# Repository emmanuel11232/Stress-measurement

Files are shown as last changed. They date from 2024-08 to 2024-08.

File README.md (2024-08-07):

# Wearable-device-for-stress-measurement-through-cardiac-parameters
Implemented a design of a device that can be used easily and comfortably, where physiological values are indicated such as body temperature, heart rate and variability heart rate, in addition to indicating the person's stress level at the time. A circuit controlled by a ProTrinket, in addition to a watch-like casing design.

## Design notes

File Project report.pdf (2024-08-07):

MUNOZ, JIMENEZ, DISPOSITIVO WEARABLE PARA EVALUACI ˜ | ON DEL ESTR ´ | ES MEDIANTE PAR ´ | AMETROS CARD ´ | ÍACOS | 1
Dispositivo wearable para evaluacion del estr ´ | es´
| mediante parametros card ´ | | | íacos
Emmanuel Munoz Pe ˜ | na, Nicole Jimenez Herrera ˜
emmanuel111232@estudiantec.cr nicojh@estudiantec.cr
Area acad ´ | emica de Ingenier ´ | ía Mecatronica ´
Instituto Tecnologico de Costa Rica ´

Resumen—Es importante tener un control del estres debido a ´ que puede afectar negativamente la salud física y emocional, así como el rendimiento academico y laboral. Al manejar el ´ estres de manera efectiva, se puede mejorar la calidad de vida y ´ bienestar en general, de ahí la importancia de un dispositivo que pueda alertar a la persona que esta pasando por un momento de ´
estres, as ´ | í poder tomar acciones y tecnicas de relajaci ´ | on. Para ´
ello, se implemento un dise ´ | no de un dispositivo que pueda ser ˜
utilizado facil y c ´ | omodamente, donde indique valores fisiol ´ | ogicos ´
como la temperatura corporal, frecuencia cardíaca y variabilidad
cardiaca, ademas de indicar el nivel de estr ´ | es de la persona ´
en el momento. Se implementa un circuito controlado por un
ProTrinket, ademas del dise ´ | no de una carcasa similar a un reloj ˜
inteligente. Finalmente, se realizaron pruebas durante el juego
Osu! dando como resultados la parametrizacion del estr ´ | es para ´
poder activar las alarmas.

Palabras clave—Dispositivo wearable, Estres, Frecuencia ´ cardíaca, Variabilidad cardíaca,

I. INTRODUCCION´
A lo largo de esta investigacion se desarroll ´ | o un dispo- ´
sitivo capaz de dar una monitorizacion continua y a largo ´ plazo de la variabilidad cardiaca, la frecuencia cardiaca y la temperatura corporal, lo que permite capturar variaciones y tendencias en el ritmo cardíaco y su relacion con los estresores ´
psicologicos y f ´ | ísicos. Ademas, al ser port ´ | atil y f ´ | acil de usar, ´
el dispositivo se integra perfectamente en la vida cotidiana del usuario, brindando una experiencia comoda y no intrusiva. Se ´
presentaran en detalle el dise ´ | no y el desarrollo del dispositivo ˜
wearable, incluyendo su arquitectura, los componentes clave y los algoritmos utilizados para el analisis de los datos. ´
De acuerdo con [1], la tecnología wearable se define como dispositivos usados en el cuerpo o en la ropa los cuales van a consistir de un receptor y un transductor los cuales
convierten las variables físicas en una senal ˜ | util para el ´
analisis digital. Entre estas nuevas tecnolog ´ | ías destaca el auge
por la monitorizacion y variabilidad card ´ | íaca. La frecuencia
cardíaca y la variabilidad de la frecuencia cardíaca (VFC) se han convertido en indicadores cruciales para evaluar la salud cardiovascular y la salud general de un individuo [2]. El calculo del VFC se puede realizar de diferentes formas, sin ´
embargo, una de las mas usadas es el valor cuadr ´ | atico medio ´
de diferencias sucesivas o RMSSD por sus siglas en ingles, ´ que como lo define [3] “es la raíz cuadrada del valor medio de la suma de las diferencias al cuadrado de todos los intervalos RR sucesivos”.

Asimismo, como lo menciona [3] si se tiene una disminu-
cion en el VFC con un aumento de la frecuencia card ´ | | | | íaca
va a dar un indicativo de fatiga o estres, adem ´ | as, se ve ´
que si se tiene una disminucion de ambas, puede deberse ´
a acumulacion de estr ´ | es. Se tiene que esta es una medida ´
sensible a las respuestas rapidas del SNA a est ´ | ímulos agudos
de estres, como el ejercicio f ´ | ísico intenso o situaciones de
estres emocional. Esto se debe a que el RMSSD mide la ´ variabilidad de corto plazo de la frecuencia cardíaca, que está influenciada principalmente por la actividad parasimpatica. ´ Adjuntando a estas mediciones la temperatura corporal se
puede obtener informacion sobre el estado psicol ´ | ogico de una ´
persona, así como la respuesta a estresores ya sea físicos o
psicologicos. Como lo muestra [4] hay una relaci ´ | on estrecha ´
entre los valores de variacion de frecuencia card ´ | íaca y el nivel
de estres psicol ´ | ogico de un individuo, de la misma forma que ´
la frecuencia cardiaca y la temperatura tienen una relacion con ´ estos, teniendo un aumento dependiendo del nivel de estres en ´ el individuo como se puede ver en lo mostrado por [5] y [6].
| II. DESCRIPCION DEL PROBLEMA ´
Para la implementacion de Monitor de Estr ´ | es se tienen dife- ´
rentes retos. El primeramente, ¿como hacer que el dispositivo ´
sea pequeno y c ˜ | omodo?. Adem ´ | as, ¿cu ´ | al modelo matem ´ | atico ´
utilizar para relacionar los valores fisiologicos de temperatura, ´ frecuencia y variabilidad cardíaca?. Tomando en consideracion los problemas planteados y el alcance de comodidad y ´ economico, se enlistan los criterios y restricciones para los ´ componentes. En general, se delimitan que los componentes
sean lo mas peque ´ | nos posibles, para comodidad, y de un precio ˜
accesible. Específicamente para el sensor de temperatura se delimita que tenga una tolerancia de < ±0,5 °C, el microcontrolador debe tener las entradas y salidas suficientes para controlar la alarma y el display y medir los datos de ambos sensores. Para la alarma, se busco que tuviera al menos 3 ´ modos de diferenciar los 3 estados de estres bajo, medio y ´ alto. Y finalmente, que todos los componentes requirieran aproximadamente de 3,3 V para solamente utilizar una batería LiPo.
III. IMPLEMENTACION DE LA SOLUCI ´ | ON´
La construccion del prototipo se divide en tres grandes ´
areas: el circuito el ´ | ectrico, con los componentes el ´ | ectricos y ´
conexiones; componentes físicos,; codigo de microcontrolador, ´ es la logica de toma de datos y el control de los actuadores. ´

MUNOZ, JIMENEZ, DISPOSITIVO WEARABLE PARA EVALUACI ˜ | ON DEL ESTR ´ | ES MEDIANTE PAR ´ | AMETROS CARD ´ | ÍACOS | 2

III-A. Circuito electrico ´

En la Fig. 1 se muestra el circuito electrico final utilizado ´ en el prototipo, donde ademas de las conexiones de todos los ´ dispositivos se detallan los pines a utilizar el microcontrolador. Por otra parte, para entender de mejor forma la conexion, se ´ puede ver el diagrama de bloques en la Fig. 2

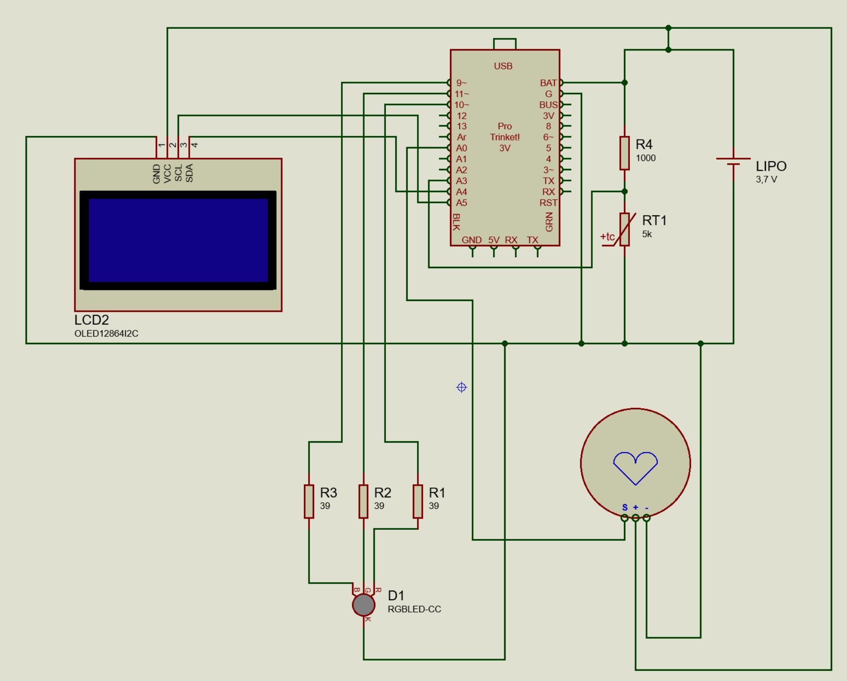
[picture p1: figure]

Figura 1. Circuito electrico implementado ´

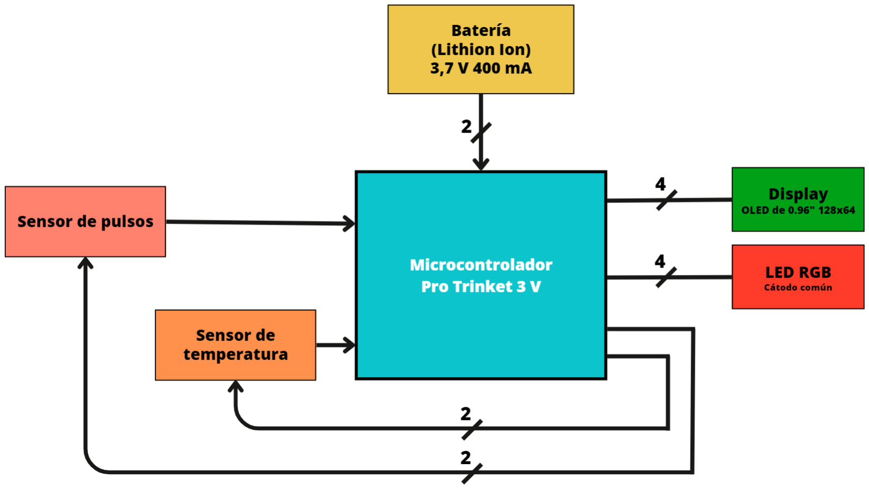
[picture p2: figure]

Figura 2. Diagrama de bloques para la conexion del hardware ´

Por otra parte, el sensor de temperatura es realizado con un Termistor NTC de 5 kΩ y una resistencia de proteccion de 1 ´
kΩ, teorico, pero su resistencia promedio real es de ´ | 981Ω.La
ecuacion caracter ´ | ística para la resistencia del termistor está
dada por la Ec. 1, tomando las características del sensor de [7].
RT = 5000e

[3975K(
1
T − | 1
298,15K )] | (1)

Por tanto, para el circuito disenado, la resistencia del termis- ˜
tor es calculada por la Ec. 2 cuando se mide su tension ( ´ | V0),
lo que finalmente despues se puede convertir en la medici ´ | on´
de temperatura con la Ec. 3. P

RT =

V0 × 981Ω
3, 7V − V0

(2)

T =

1
298, 15K

−

ln RT
5000Ω
3975K

!−1
− 273, 15K (3)

Por ultimo, el actuador seleccionado corresponde a una ´
RGB de 5 mm, con catodo com ´ | un. Se utiliza para todos los ´
colores (R: rojo, B: azul, G: verde) una resistencia de 39 Ω para limitar la corriente a menos de 20 mA. Para el control de apagado y encendido de cada color se hace uso de los PWM del Trinket, utilizando los pines 9, 10, 11. Físicamente, todos estos componentes fueron soldados en una placa de cobre perforada con fibra de vidrio.

III-B. Componentes físicos
Se construyo un modelo 3D de una carcasa para hacer el ´
dispositivo facil y capaz de ser ´ | wearable. Para este prototipo
se eligio utilizar el dispositivo en el brazo, por lo que las ´
consideraciones de diseno es que fuera lo m ˜ | as compacto ´
posible el modelo 3D. En la Fig. 3 se observa la carcasa superior, sus características mas importantes es que es donde ´ se van a colocar los actuadores del dispositivo, la pantalla OLED y la LED RGB. Sus medidas principales son 42 mm de ancho, 45 mm de largo y 7 mm de alto. Se disenaron las ˜
fijaciones mediante una presilla voladiza basica para la uni ´ | on´
de ambas carcasas, tambien unas peque ´ | nas extrusiones en las ˜
esquinas para evitar que las dos mitades se separen. Ademas, ´ se le agregaron unas extrusiones de 2 mm de diametro para ´ poder sujetar la pantalla OLED sin necesidad de tornillo, sino
despues colocar unas gotas de silic ´ | on caliente. ´

Figura 3. Vista isometrica de la carcasa superior ´

Para el diseno de la carcasa inferior, Fig. 4, se tom ˜ | o en ´
consideracion que adentro de la carcasa se colocaran los dos ´ sensores, en la parte inferior, seguido de la placa para soldar,
el Trinket y por ultimo la bater ´ | ía. Por lo anterior, sus medidas
son de 42 mm de ancho, 45 mm de largo y 29 mm de alto. Para la union de ambas partes, en esta carcasa se agrega la ´ cavidad de la presilla. Se agregaron dos ranuras a cada lado de la carcasa para incorporar un elastico al dispositivo, lo que ´ facilita el agarre del dispositivo en el brazo.

Figura 4. Vista isometrica de la carcasa inferior ´

III-C. Codigo para microcontrolador ´
Para el calculo de los par ´ | ametros card ´ | íacos se realizo una ´
deteccion de flancos positivos y negativos para determinar el ´ pico de cada latido, con esto se midio el tiempo entre cada ´
medicion para poder obtener los intervalos entre picos ´ | | “R” de
cada latido. Esta informacion fue de vital importancia para el ´
calculo del VFC y de FC mediante las f ´ | ormulas en Ec. 4 y ´
Ec. 5 respectivamente, donde N serían la cantidad de datos tomados, para en un intervalo de 15 s sería N = 50, medido al final de cada toma de datos respectivamente.

RMSSD =

### vuut

1
N − 1

X

N

i=1

(Ri − Ri−1)

2 | (4)

MUNOZ, JIMENEZ, DISPOSITIVO WEARABLE PARA EVALUACI ˜ | ON DEL ESTR ´ | ES MEDIANTE PAR ´ | AMETROS CARD ´ | ÍACOS | 3

F C =

1
N

X

N

i=1

Ri | (5)

Se presentan los diagramas de flujo en las Fig. 5 y 6
que ahonda mas en la explicaci ´ | on de dichos c ´ | alculos y su ´
programacion en el microcontrolador Trinket. ´

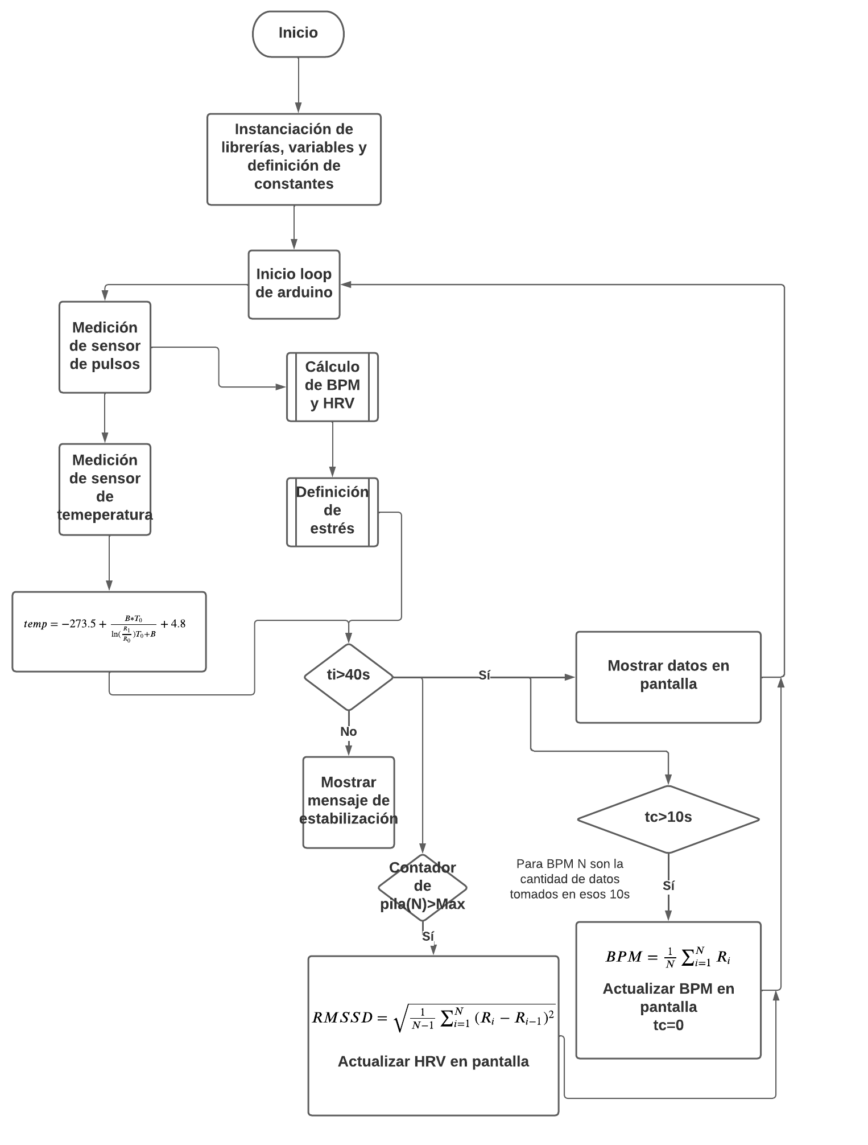
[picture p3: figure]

Figura 5. Programacion para FC e intervalos mediante detecci ´ | on de flancos ´

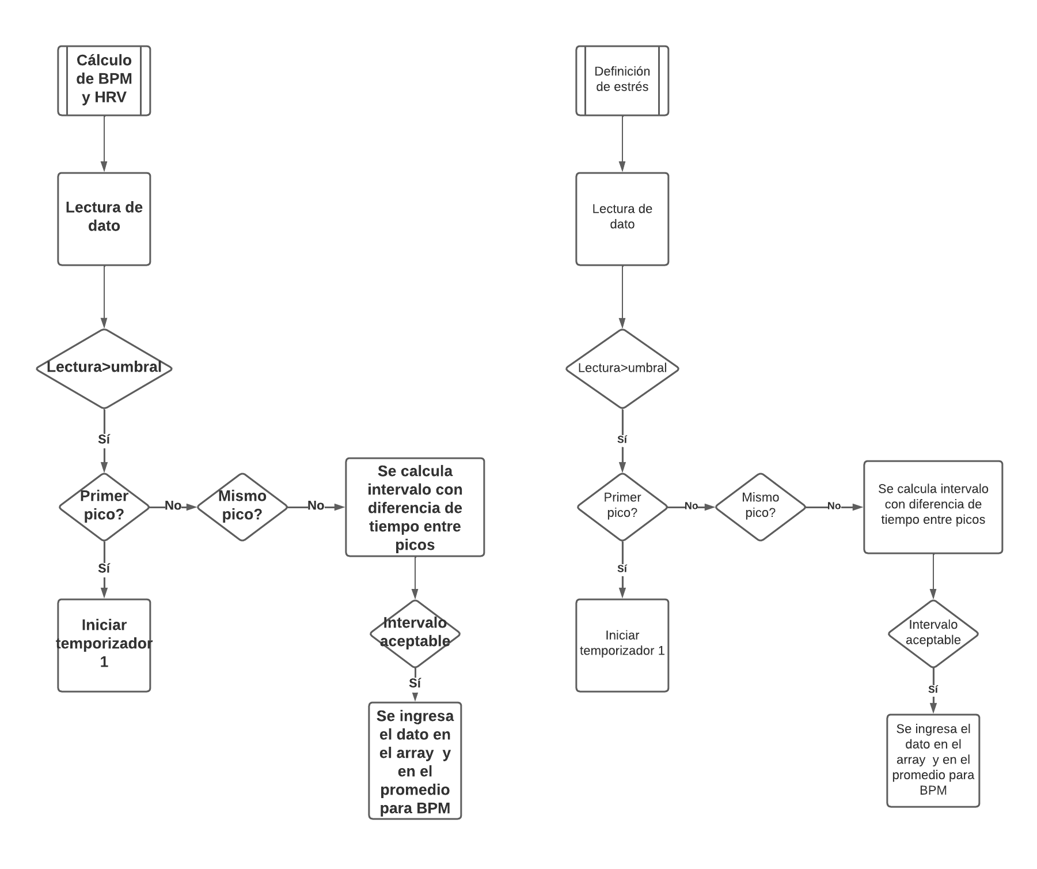
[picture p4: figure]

Figura 6. Diagrama de flujo para funciones de definicion de estr ´ | es y c ´ | alculos ´
III-D. Definicion de estr ´ | es´
Para la determinacion de cu ´ | ando la persona tiene estr ´ | es, se ´
utilizo normalizaci ´ | on de los datos de la persona a prueba. Se ´
hizo una medicion donde la persona estaba lo m ´ | as tranquilo ´
posible, donde sus valores fueron los siguientes:
Frecuencia cardíaca: 77 - 85 BPM
Variabilidad cardíaca: 44,11 - 54,05 ms
Temperatura: 36,2°C
Y para un estado bajo estres emocional y f ´ | | ísico, sus valores
fisiologicos fueron los siguientes: ´
Frecuencia cardíaca: 95 BPM
Variabilidad cardíaca: 38,7 ms
Temperatura: 36,5°C

Tomando dichos valores de referencia, se calculan valores
maximos y m ´ | ínimos y se realiza la normalizacion de los ´
datos de FC, VFC y temperatura con las ecuaciones 6,7 y 8 respectivamente.

F Cnor =

F Cmedida − 70BPM
50BPM
× 35 % | (6)

V F Cnor =

1 −

V F Cmedida − 30ms

30ms |
× 50 % | (7)

Tnor =

Tmedida − 35◦C
3

◦C

× 15 % | (8)
IV. ANALISIS DE LA SOLUCI ´ | ON´
Se realizo una prueba de comprobaci ´ | on de la lectura para ca- ´
da uno de los sensores. Para los pulsos cardíacos, se comparó con un reloj inteligente que mide frecuencia cardíaca; para la
temperatura se utilizo un term ´ | ometro digital. Los resultados de ´
la prueba de frecuencia cardiaca se muestran en el cuadro I, donde se obtuvo que la diferencia entre el dispositivo monitor de estres tiene una diferencia en promedio de 3,58 BPM de ´ la medicion del reloj, lo que se puede considerar como la ´ exactitud del sensor tomando como “valor real” la medicion´ del reloj inteligente, no obstante, este dispositivo por igual tiene un valor de incertidumbre relacionado y no se obtuvo tal dato. Las diferencias mas grandes pueden ser causados debido ´
a errores durante la medicion de hasta un peque ´ | no movimiento ˜
en falso que pudiera afectar las lecturas del sensor.

Cuadro I
COMPARACION ENTRE LA FRECUENCIA CARDIACA ´ | (FC) DEL MONITOR
| DE ESTRES´ (M.E) Y UN RELOJ INTELIGENTE
FC M.E (± 1 BPM) | FC Reloj (± 1 BPM) | ∆FC (BPM)
85 | 86 | 1
89 | 87 | 2
86 | 86 | 0
81 | 70 | 11
95 | 95 | 0
89 | 93 | 4
92 | 90 | 2
87 | 86 | 1
86 | 80 | 6
85 | 75 | 10
92 | 87 | 5
92 | 93 | 1
Promedio | | 3,58

De la misma forma, los resultados obtenidos de la prueba de temperatura se muestran en el cuadro II, donde se determinó que la diferencia promediada entre el dispositivo y el termome- ´
tro es de 5°C, este dato se tomo para calibrar la ecuaci ´ | on del ´
termometro. ´
Por otra parte, tambien se hizo dos pruebas del dispositivo ´
con una persona de prueba durante una situacion de estr ´ | es. El ´
escenario de prueba se escogio que fuera una partida jugando ´ Osu!, el cual es un videojuego de ritmo que consiste en rastrear un objetivo en pantalla con un mouse o trackpad y luego presionar con precision un par de teclas al tiempo con las ´ indicaciones y la musica. Estas indicaciones pueden ser una ´ línea para trazar, puntos para golpear, ruedas giratorias para girar y otros patrones mas complejos. Por tanto, este juego ´ propicia un ambiente de estres emocional para las personas. ´ En el cuadro III se muestra de los valores fisiologicos ´ medidos con el dispositivo Monitor de Estres en la prueba N°1. ´

MUNOZ, JIMENEZ, DISPOSITIVO WEARABLE PARA EVALUACI ˜ | ON DEL ESTR ´ | ES MEDIANTE PAR ´ | AMETROS CARD ´ | ÍACOS | 4

Cuadro II
COMPARACION ENTRE LA MEDICI ´ | ON DE TEMPERATURA CORPORAL DEL ´
MONITOR DE ESTRES´ (M.E) Y TERMOMETRO DIGITAL ´
Temperatura M.E (± 0,13 °C) | Termometro ( ´ | ± 0,1 °C) | ∆T (°C)
32,04 | 35,7 | 3,66
31,45 | 36,2 | 4,75
31,07 | 36,1 | 5,03
31,07 | 36,1 | 5,03
31,26 | 36,20 | 4,94
31,07 | 36,1 | 5,03
31,07 | 36 | 4,93
30,7 | 36 | 5,3
30,5 | 36 | 5,5
30,69 | 35,9 | 5,21
30,31 | 35,9 | 5,59
Promedio | | 5,00

Durante esta prueba, el termistor aun no estaba calibrado. Por ´ otra parte, se observa que en los primeros momentos la persona se encuentra en sus estados normales de valores fisiologicos, ´ mientras avanza en el juego, su variabilidad cardíaca va disminuyendo y su frecuencia cardiaca aumenta, como era
de esperar. Su momento mas estresante es en la medici ´ | on 5, ´
utilizando la normalizacion propuesta, la suma de todos sus ´
valores fisiologicos da un 57,16 %. En cambio, en la medici ´ | on´
1 resulta en 36,23 % y en la recuperacion 36,23 %. ´

Cuadro III
VALORES FISIOLOGICOS DURANTE LA PRUEBA ´ | N°1 DURANTE EL JUEGO

DE OSU!

Momento | FC (± 1 BPM) | VFC (± 0,01 ms) | Temperatura (± 0,13 °C)
1 | 98 | 55,12 | 34,03
2 | 103 | 46,05 | 34,03
3 | 108 | 46,05 | 34,03
4 | 100 | 41,80 | 34,03
5 | 95 | 41,0 | 33,93
6 | 100 | 44,54 | 34,00
7 | 93 | 43,49 | 33,93
Recuperacion´ | 82 | 50,74 | 33,93

Siguiendo la misma forma, se hizo una segunda prueba
con el juego pero con otra cancion, en esta ocasi ´ | on se utiliz ´ | ó
el termometro digital dado que en la primera a ´ | un no estaba ´
calibrado, y se requiere tambien valores con otros dispositivos ´ de medicion para tener certeza del comportamiento de la ´ temperatura ante el estres. Los resultados se muestran en el ´
cuadro IV. Para esta ocasion, el momento m ´ | as estresante se ´
encuentra en la medicion 6, donde la suma de los valores ´ normalizados es de 66,43 %. En cambio, en el momento 1 la suma es de 37,6 % y en la recuperacion 40,05 %. ´
Con los resultados anteriores, se observa de forma cuantita-
tiva el estres y con la normalizaci ´ | on se puede determinar los ´
parametros para el estr ´ | es, los cuales son: ´
Estado Tranquilo: Total<45 %
Estado Agitado: 45 %<Total<55 %
Estado Estresado: Total>55 %
Estos parametros fueron elegidos y comprobadas de acuerdo ´ a las mediciones en estado tranquilo y estado estresado de la persona, tanto en las pruebas realizadas como con los datos utilizados en la normalizacion. Al igual que las ecuaciones ´

Cuadro IV
VALORES FISIOLOGICOS DURANTE LA PRUEBA ´ | N°2 DURANTE EL JUEGO

DE OSU!

Momento | FC(± 1 BPM) | VFC(± 0,01 ms) | Temperatura (± 0,13 °C)
1 | 90 | 50,64 | 36,6
2 | 86 - 92 | 46,41 | 36,2
3 | 100 | 47,87 | 36,7
4 | 103 | 47,87 | 36,7
5 | 101 - 98 | 40,79 | 36,6
6 | 101 | 37,96 | 36,6
Recuperacion´ | 93 | 50,43 | 36,6

normalizadas pueden variar dependiendo de la persona y sus
valores fisiologicos de estado normal, sin ning ´ | un estr ´ | es f ´ | ísico
o psicologico. ´
V. CONCLUSIONES
Se logro la determinaci ´ | on de una correlaci ´ | on entre el ´
estres, la variabilidad card ´ | | íaca, la frecuencia cardíaca
y la temperatura, gracias a la normalizacion de datos, ´ y se obtuvo que la variabilidad cardíaca junto con la frecuencia cardíaca son los principales indicativos de estres en una persona. ´
Se determino que el c ´ | alculo de variabilidad card ´ | íaca
mediante RMSSD era el mas adecuado ante estresores ´
a corto plazo debido a la relacion entre esta medici ´ | on y ´
la actividad en el sistema nervioso parasimpatico. ´
Se logro una medici ´ | on, con un error de 3,58 BPM con ´
respecto a un dispositivo wearable del mercado, de los latidos cardíacos, su ritmo y variabilidad mediante el uso de un sensor de latidos cardíacos y un microcontrolador
para la interpretacion de las se ´ | nales recibidas, su filtrado ˜
y el despliegue de la informacion en una pantalla. ´
Se obtuvo la medicion de la temperatura corporal de un ´ individuo mediante el uso de un termistor como sensor de temperatura obteniendo un error de 5°C con respecto a un dispositivo de medicion de temperatura corporal del ´
mercado y su relacion con el estr ´ | es. ´

VI. RECOMENDACIONES

Se recomienda utilizar otro sensor de temperatura mas´
comodo y con mayor precisi ´ | on, ya que la lectura de ´
temperatura del termistor puede ser afectado por factores
como auto-calentamiento, ademas de que es m ´ | as dif ´ | ícil
su implementacion por su fragilidad y poca flexibilidad. ´ El sensor de pulsaciones utilizado tiene una gran sensibilidad ante el movimiento y otros factores que hagan que la luz no se reciba correctamente de vuelta, por lo que se recomienda tener un filtrado constante de las senales ˜ recibidas para lograr obtener datos mas precisos. ´
Se recomienda llevar a cabo estudios adicionales para fortalecer y ampliar las conclusiones obtenidas, entre estas se puede tomar el estudio en mayor cantidad de individuos, ya que el dispositivo fue calibrado para solo una persona, tambien se pueden llevar a cabo medicio- ´ nes por lapsos de tiempo mayores para poder obtener
informacion m ´ | as amplia sobre estresores cr ´ | onicos. ´

MUNOZ, JIMENEZ, DISPOSITIVO WEARABLE PARA EVALUACI ˜ | ON DEL ESTR ´ | ES MEDIANTE PAR ´ | AMETROS CARD ´ | ÍACOS | 5

REFERENCIAS

[1] Xie, J., Chen, Q., Shen, H., & Li, G. (2020). Review—Wearable Graphene Devices for Sensing. Journal of The Electrochemical Society, 167(3), 037541. doi:10.1149/1945-7111/ab67a4
[2] Duncker, D., Ding, W. Y., Etheridge, S., Noseworthy, P. A., Veltmann, C., Yao, X., . . . Gupta, D. (2021). Smart Wearables for Cardiac Monitoring—Real-World Use beyond Atrial Fibrillation. Sensors, 21(7), 2539. doi:10.3390/s21072539
[3] F. J. Forner Llacer, “La variabilidad de la frecuencia card ´ | íaca como
indicador de fatiga en el futbol profesional”, Tesis doctoral, Universitat ´ Catolica de Valencia, Valencia, 2021. ´
[4] S. Boonnithi and S. Phongsuphap, Comparison of heart rate variability measures for mental stress detection, 2011 Computing in Cardiology, Hangzhou, China, 2011, pp. 85-88.
[5] Tendulkar, A. P., Victorino, G. P., Chong, T. J., Bullard, M. K., Liu, T. H., & Harken, A. H. (2005). Quantification of Surgical Resident Stress “On Call”. Journal of the American College of Surgeons, 201(4), 560–564. doi:10.1016/j.jamcollsurg.2005.05.004
[6] Vinkers, C. H., Penning, R., Hellhammer, J., Verster, J. C., Klaessens, J.
H. G. M., Olivier, B., & Kalkman, C. J. (2013). The effect of stress on core and peripheral body temperature in humans, Stress, 16(5), 520–530. doi:10.3109/10253890.2013.807243
[7] H Zhang, “NTC Thermistor TTC 03 Type”, Thinking Electronic Industrial, Kaohsiung, Taiwan, Tech, TTC3A502G39HAEY, Nov. 2021.
[8] Y. Gitman. “Heartbeats in Your Project”. World Famous Electronics llc. https://pulsesensor.com/ (accedido el 5 de junio de 2023).

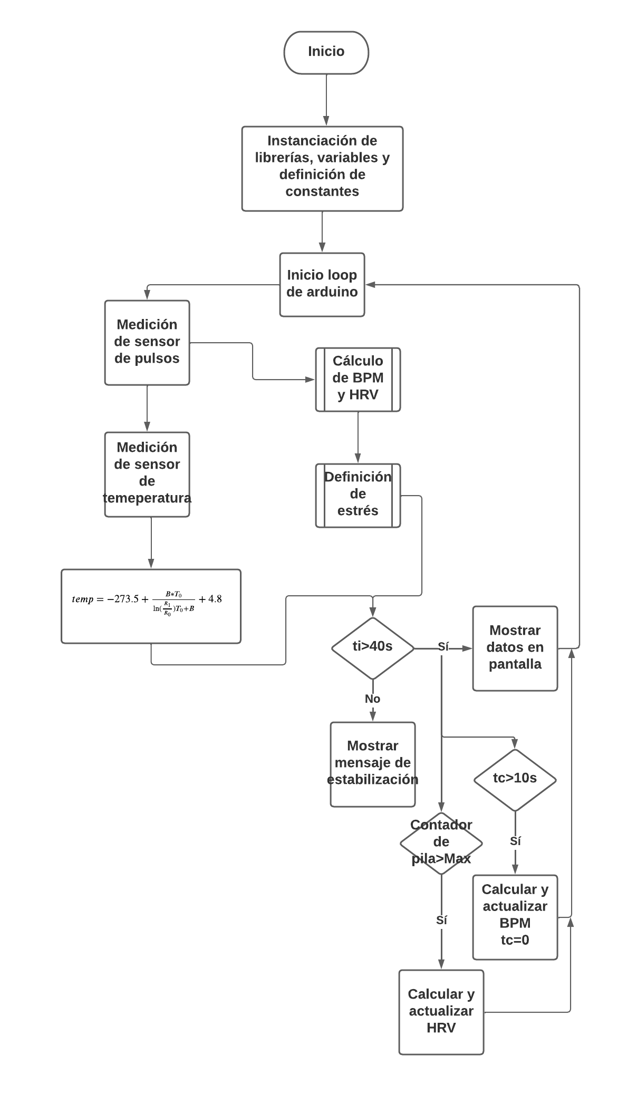
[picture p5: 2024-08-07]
Diagrama de flujo principal.png

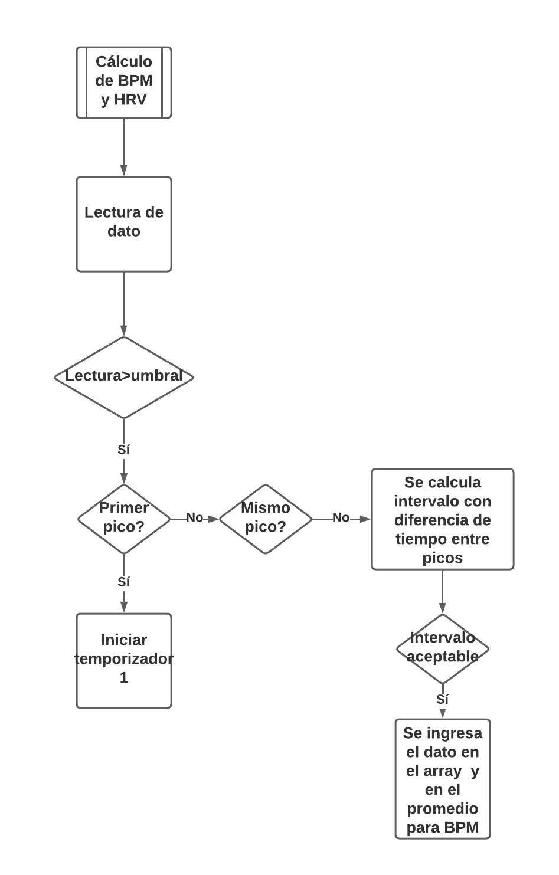
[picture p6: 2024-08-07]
Diagrama calculo de HRV y BPM.png

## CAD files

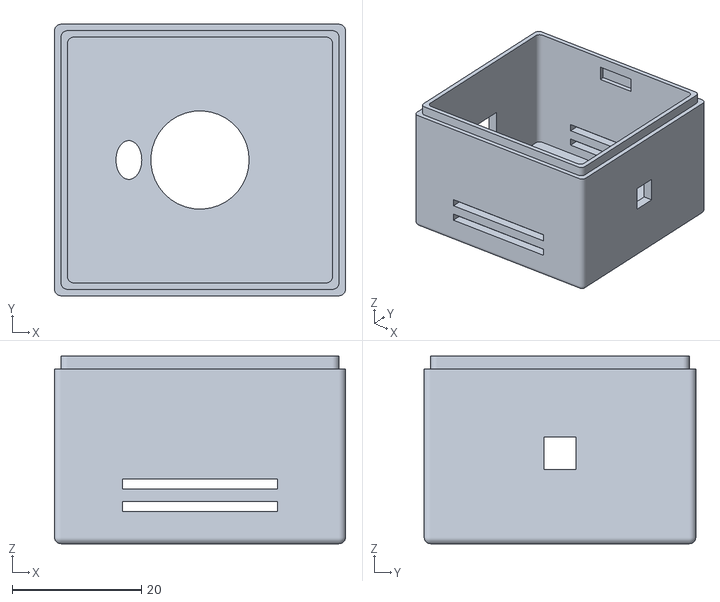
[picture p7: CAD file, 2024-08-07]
Pieza-abajo-final.STL
45.0 x 42.0 x 29.0

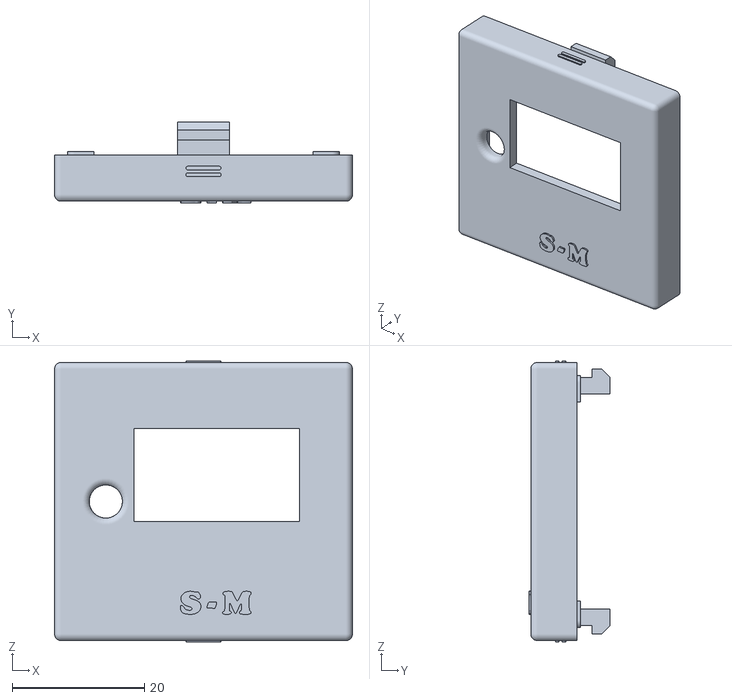
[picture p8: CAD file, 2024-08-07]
Pieza-Arriba-FINAL.STL
45.0 x 12.3 x 42.4
